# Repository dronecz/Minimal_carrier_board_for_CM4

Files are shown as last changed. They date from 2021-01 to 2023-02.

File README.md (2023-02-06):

# Minimal carrier board for Compute Module 4

This board is based on design from [Prof. Fartsparkle´s](https://hackaday.io/project/175832-minimal-raspberry-pi-cm-4-carrier). I made it 2 layer board and changed slot for SD card. 

If you are interested, I have some boards for you at my [Tindie](https://www.tindie.com/products/dronecz/minimal-carrier-board-for-compute-module-4/) store. 

You can also find STEP files for revision A and D in _STEP files_ directory. 

##### A designed following revisions:

- **rev.A**

This is just copy of the design from Timon. I just added 2x7 pin header and made shape of the board to the size of the Einsy board so I can use it for Octoprint. 

Board is tested and working. There is UART connection at that 2x7 pin header connected to the GPIO´s at CM4. There is slight problem with cables for HDMI and USB, but it can be solved with right cables.  

**WARNING** : The pinout for Einsy board is mirrored so I do not take any responsibility for damage which can be cause by this. You can change that in files and made your own board.

- **rev.B** 

I redesigned whole board and made it little bit bigger. Added 3.2mm mounting holes to each corner, added boot button for versions of CM4 with eMMC onboard (working), added connector for camera and added standard 40-pin header for Raspberry Pi.

I did not made this board yet but I did test distances between cables and rearanged them so they should not colide. Height of camera connector should be OK beneeth CM4, but this need to be tested. 

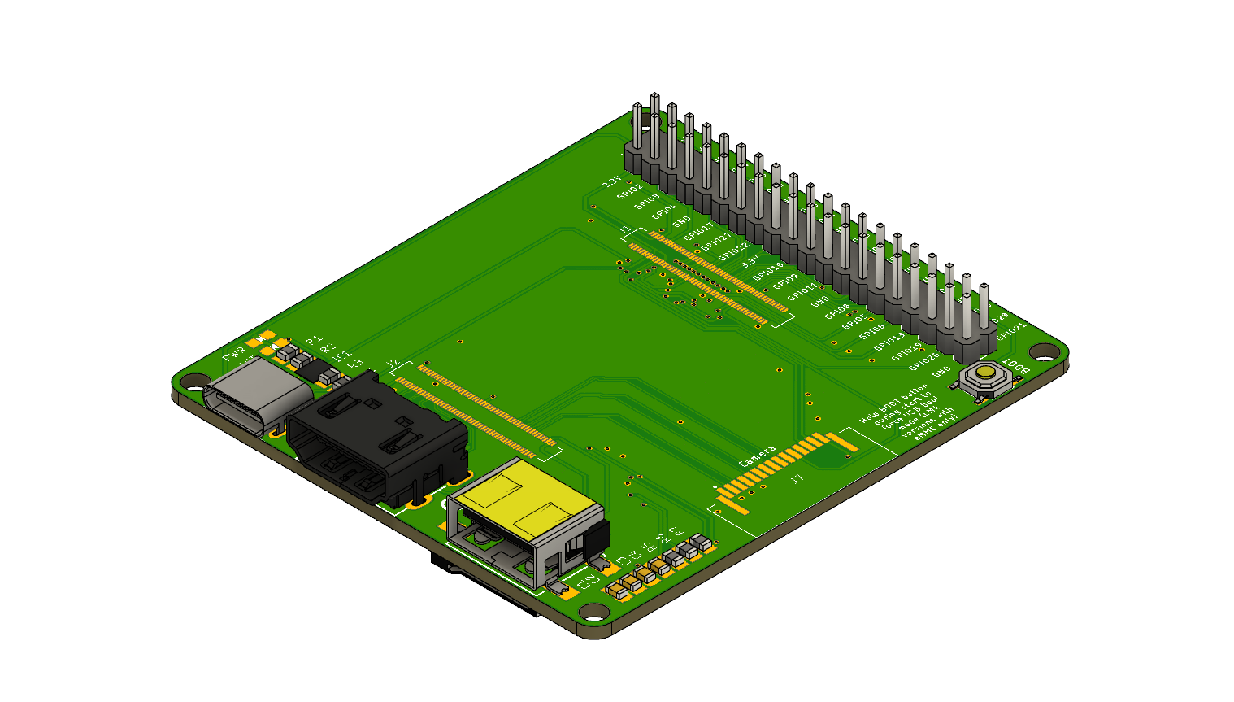
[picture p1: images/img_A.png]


- **rev.B_alt**

This is same board as rev.B, but there are 22-pin connectors which are same as those used at official IO board. 

This version of the board was not manufactured and probably will never be. 

- **rev.C**

Layout of the board is same with **rev.B** but I did move CM4 about 2 mm up and camera connector about 1 mm down. Half of the board was routed again .**This revision was not manufactured and it is not tested!** 

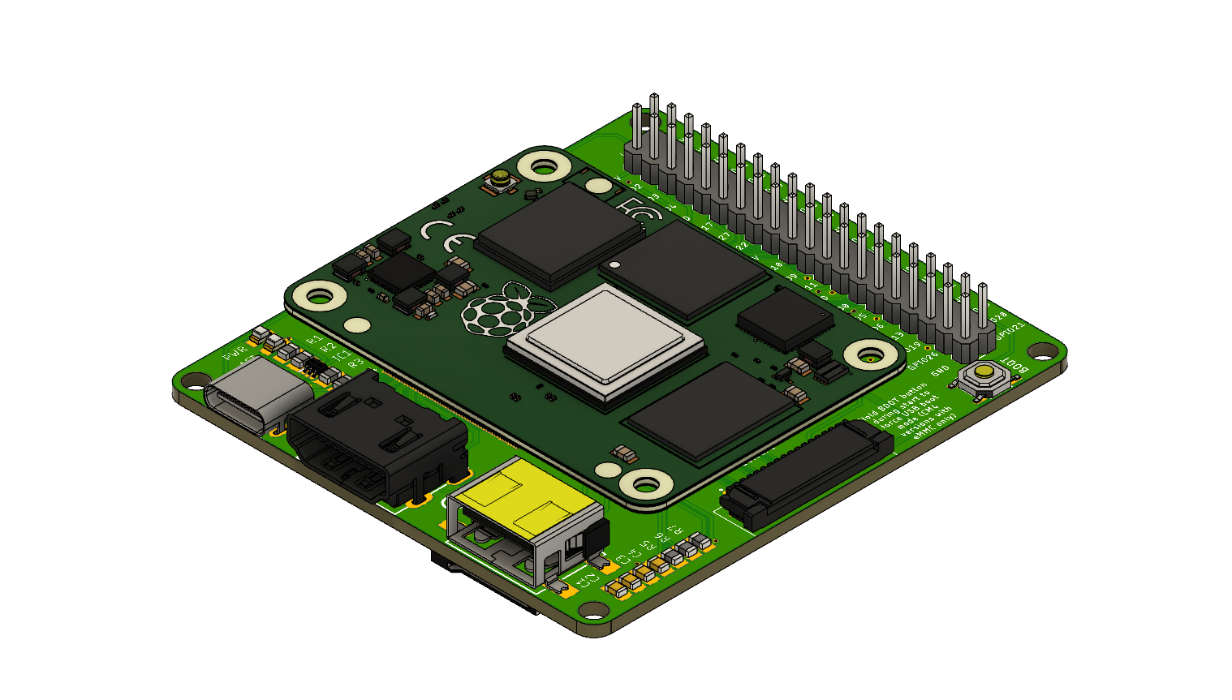
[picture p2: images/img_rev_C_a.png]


- **rev.D**

This version of the board is working, except camera connector because I did not routed camera connections as differential pairs. I made and sold about 30 boards without any complains, so the design is validated. 

- **rev.E**

This is same board as rev.D, but with differential pairs fix for camera connector. **This revision was not yet manufactured so I can not garantee that the connector for camera will work.**

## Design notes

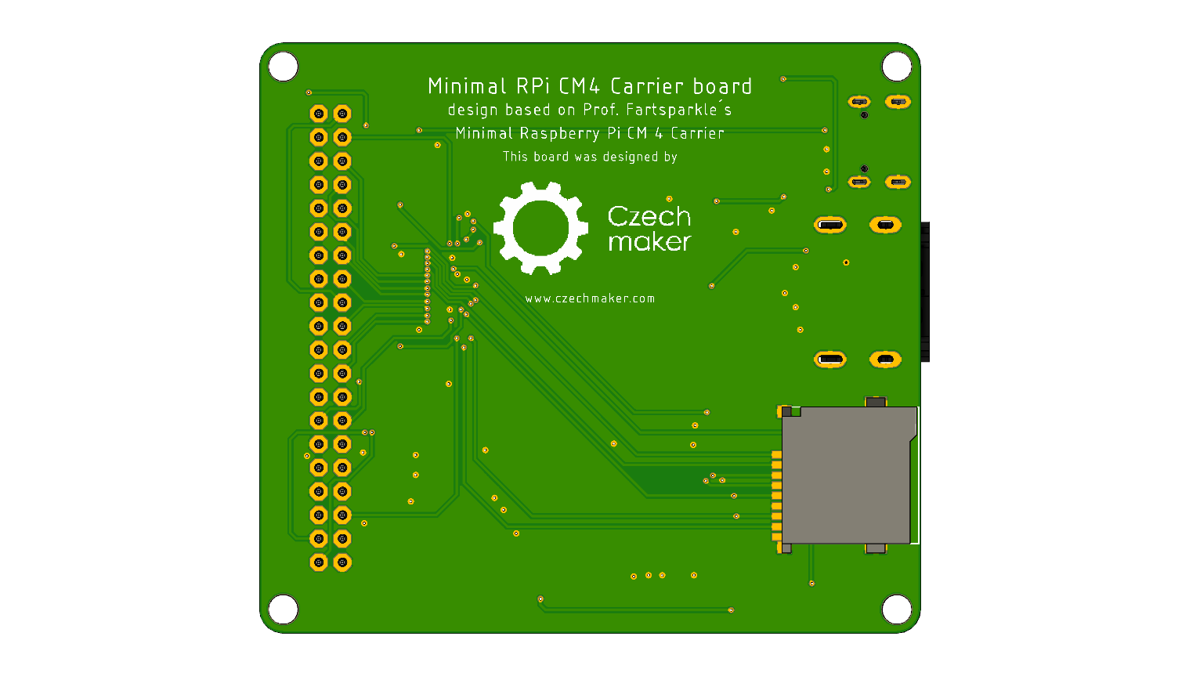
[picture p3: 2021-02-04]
images/img_C.png

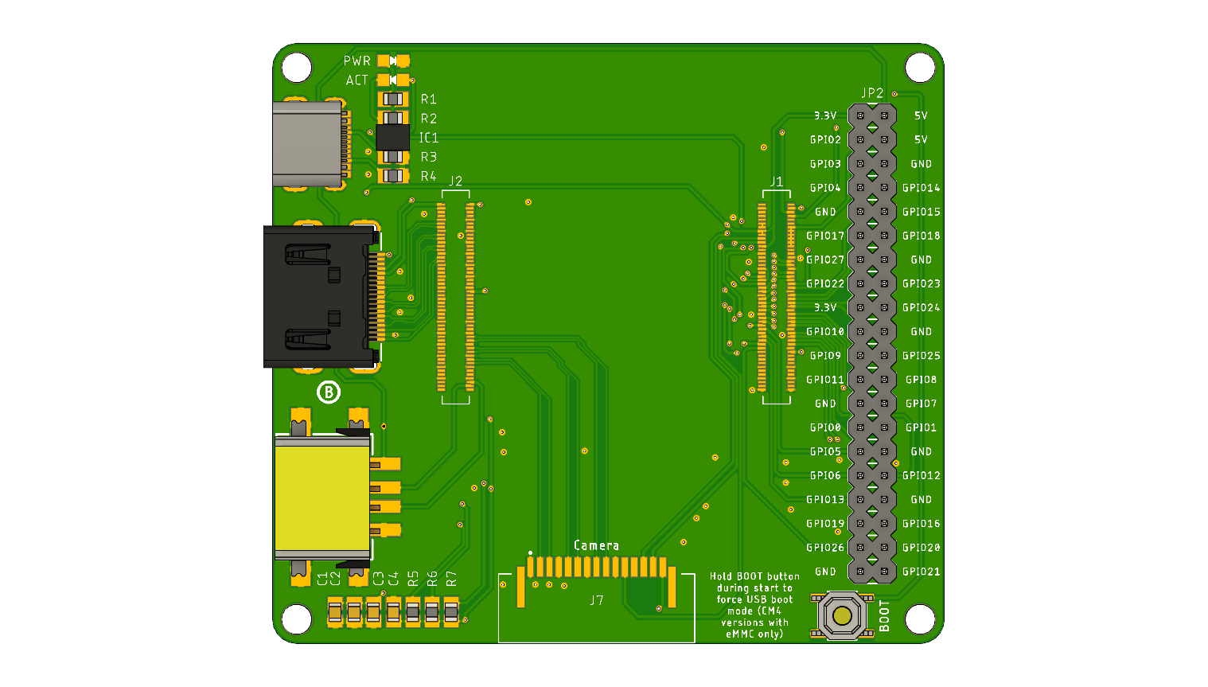
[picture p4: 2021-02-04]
images/img_B.png

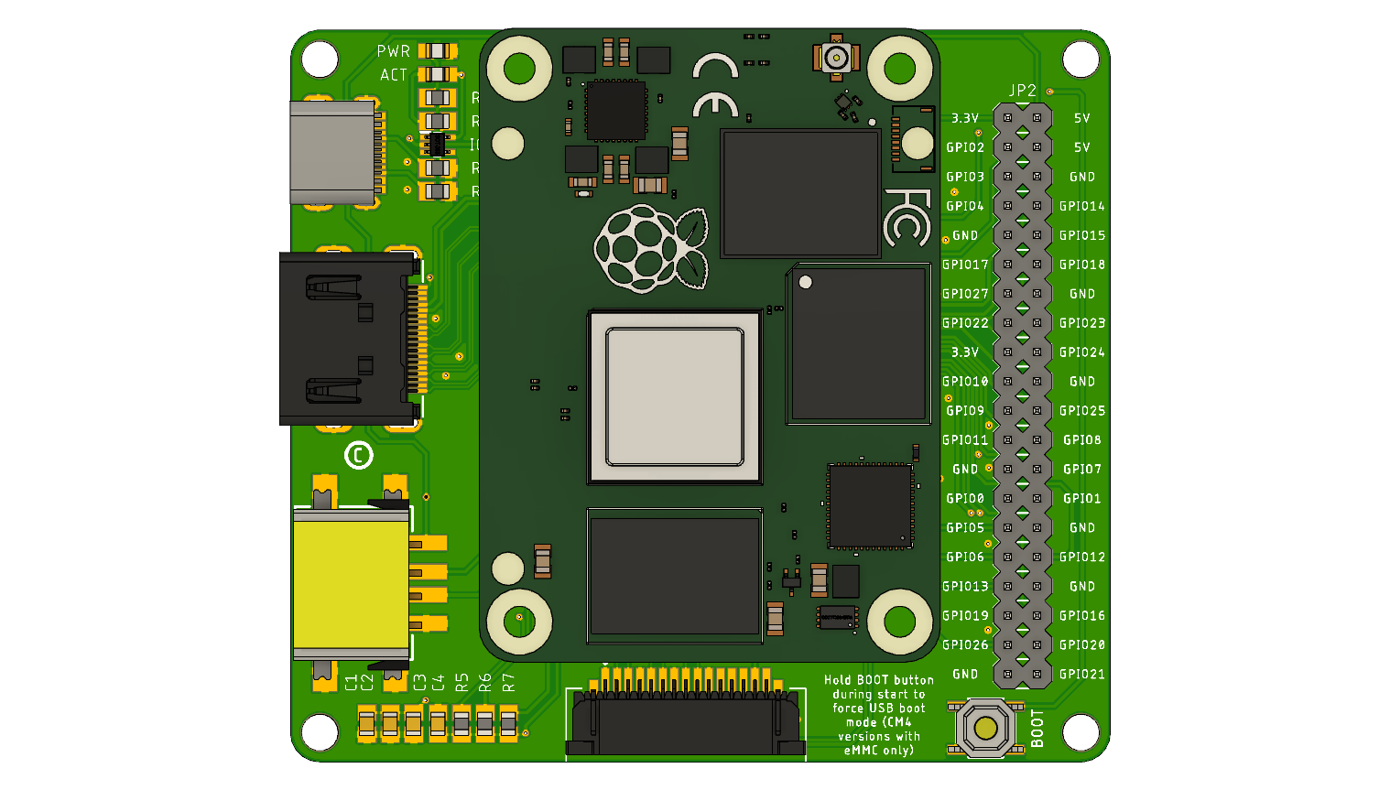
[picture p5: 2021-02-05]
images/img_rev_C_b.png

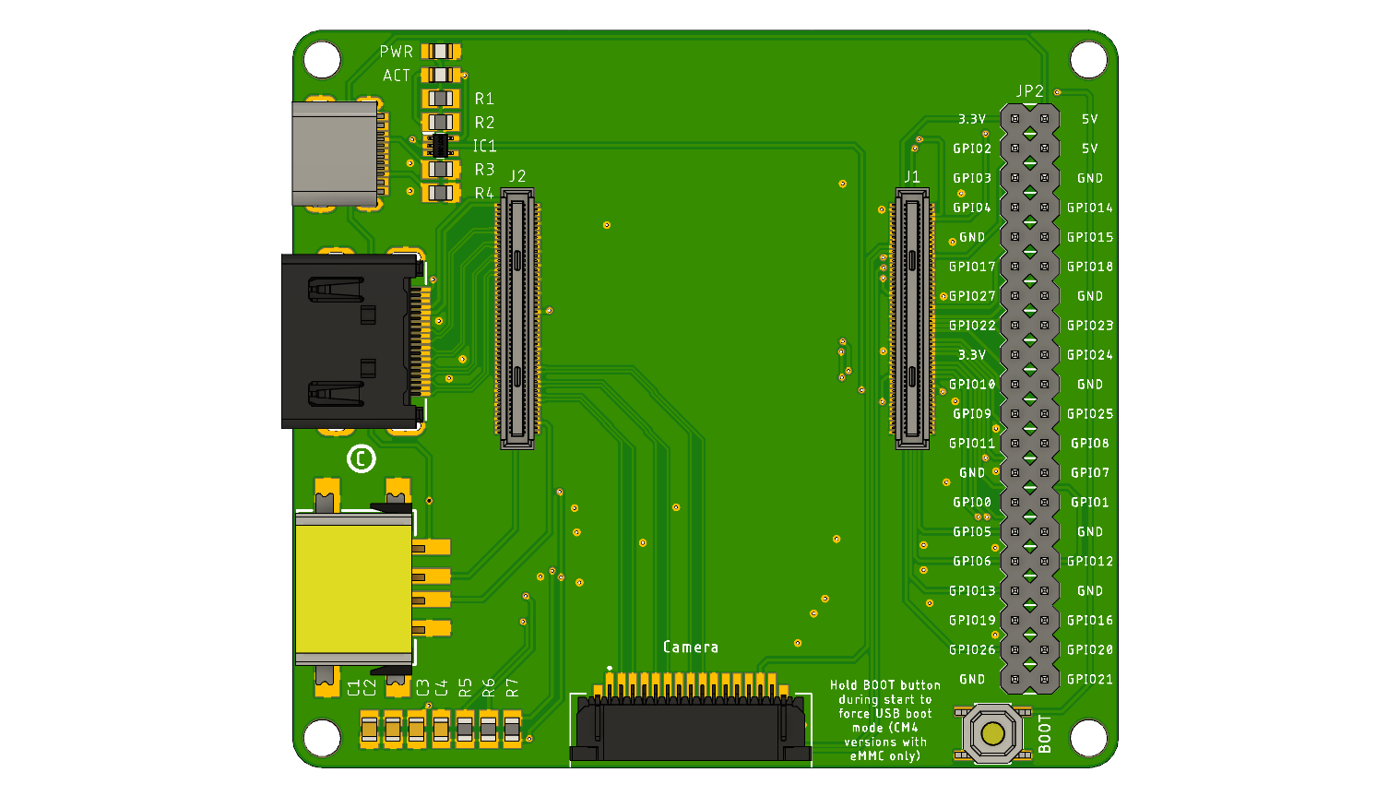
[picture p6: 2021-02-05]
images/img_rev_C_c.png

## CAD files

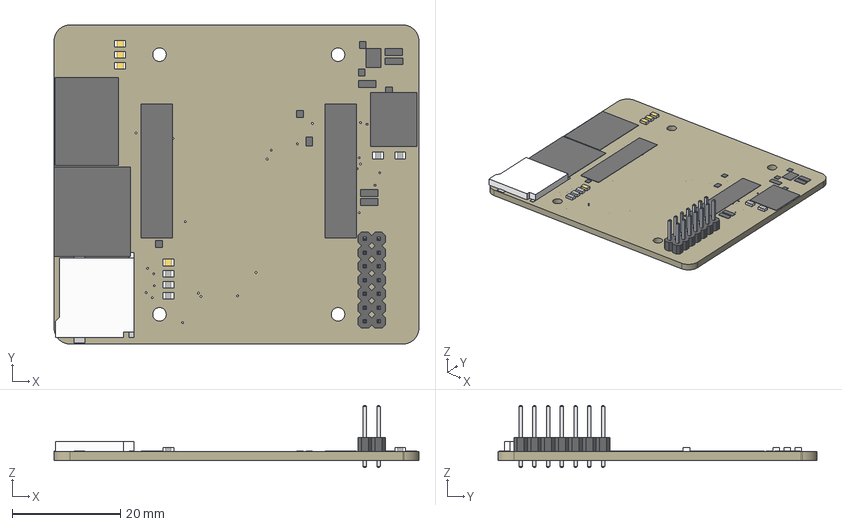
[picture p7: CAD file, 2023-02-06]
STEP files/Minimal_carrier_board_for_CM4_rev_A .step
67.5 x 59.0 x 11.5 mm
Board
USB-A-F-PTH
USB-TYPE-C_16PIN-MALE-TYPE-C-31-M-12
DF40C100DS04V51 x 2
SOT65P210X110-5N
PAD.03X.05 x 5
SMT-JUMPER_2_NC_TRACE_NO-SILK
TFP09-2--12B
CHIPLED_0805_NOOUTLINE x 2
HDMI_MOLEX_47151-0001
_0805MP x 3
2X07
C0805 x 4
R0805 x 5

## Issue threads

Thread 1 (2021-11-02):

Schematics pdf

jaksatomovic, 2021-11-02:
Can you please share schematics in pdf format, since this can't be opened in KiCad? Thx

dronecz, 2021-11-02:
HI,

I can, but which version you have in mind? I do not use it, but I know that KiCad can import Eagle projects.

jaksatomovic, 2021-11-02:
Hi, thx for the quick reply. I was thinking on latest version…C

dronecz, 2021-11-02:
[Here](https://github.com/dronecz/Minimal_carrier_board_for_CM4/blob/main/rev_C/Minimal_carrier_board_for_CM4_rev_C.pdf) you have it 😉

jaksatomovic, 2021-11-02:
Thank you!

Closed 2021-11-02.

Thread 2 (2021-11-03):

Csi; cam1 missing datalines 2 and 3

rraat, 2021-11-03:
Unfortunataly the csi interface is a 15 pin connector and the 2 additional data lines are not implememted
Would be great if the csi connector could be replaced with a mini connector (22 pin as found on the pi zero) that way we could attach a tc358743 module for hdmi input)

dronecz, 2021-11-03:
I choosed CSI connector so you can use RPi Camera module straight away without any reduction or without need of 22 to 15 pin cable which is used for RPI Zero. Connector is wired per CM4 IO board schematic:
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

I do not plan to change connector or add other lines, but you can do so, as you have all files which you need for that.

samveen, 2021-11-06:
As someone who had to purchase the 22 to 15 pin cable, I find the full sized connector way more useful, given that the correct cable is supplied along with most camera modules in the Raspberry Pi ecosystem.

munjeni, 2023-12-29:
You pcb is very bad, simply bad layout. Too long data lines act as an high freq antena. Too long 3.3V lie, it going to pickup all noise from fast daa lines. Also you must separate ground from signal ground and connect it at input supply capacitor in star coonection at one point at supply input capacitor. You must have 4 layer pcb and put supply lines/gnd line inside central layers, lines one over other to form an small capicitivity and have less noise pickup, fast data lines on top layer only, bottom layer as a shield layer call it gndref laye cnnected with all other gndref layer shields, connect all gndref layers at one point in star at supply input capacitor... etc.

dronecz, 2023-12-29:
> Your pcb is bad, simply bad layout. Too long data lines act as an high freq antena. Too long 3.3V lines, it going to pickup all noise from fast data lines. Also you must separate ground from signal ground and connect it at input supply capacitor in star coonection at one point at supply input capacitor. You must have 4 layer pcb and put supply lines/gnd line inside central layers, lines one over other to form an small capicitivity and have less noise pickup, fast data lines on top layer only, bottom layer as a shield layer call it gndref layer cnnected with all other gndref layers, connect all gndref layers at one point in star at a one point at a supply input capacitor. Lack of boiler capacitors, lack of supression capacitors... etc.. Put camera connector, usb connector, hdmi connector as close as possible to cm4 pins. Put signaling led on bottom/right side. Layout is very bad. The only thing which I like is it looks nice, the other things very bad.

Thank you for your review. If you do not like it, then you can fork it, make it better and I would merge your PR.

munjeni, 2023-12-30:
Your pcb looks good, you started it nice but I not like how you route thing, I will do it when I get some free time! I just started routing it, looks better? RefGND is a star point where your signal gnd lines must be routed, group it, for example group gnd signal lines from for example sd card and route to the star gndref, than the same for e.g. hdmi ground lines... etc. The same for 5V and 3.3V. GND from sockets metal can be routed directly to big gnd line but. All signal lines put on top layer only... See example!
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

munjeni, 2023-12-30:
Some more work
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

munjeni, 2023-12-30:
For you from me and for me too! Complete project files, pictures, schematic, gerber, bom. All shield layers is connected in star ground as all other gnd things. Supply lines isolated, signal lines isolated too. I done my best to route it correctly, hope it will be usefull.

[MinimalCarrierBoardForCM4_Munjeni.zip](https://github.com/dronecz/Minimal_carrier_board_for_CM4/files/13798436/MinimalCarrierBoardForCM4_Munjeni.zip)

munjeni, 2023-12-30:
Oh sorry, one hole was covered by sdcard slot, this is corrected gerber file

[Gerber_PCB_MinimalCarrierBoardForCM4.zip](https://github.com/dronecz/Minimal_carrier_board_for_CM4/files/13798978/Gerber_PCB_MinimalCarrierBoardForCM4.zip)

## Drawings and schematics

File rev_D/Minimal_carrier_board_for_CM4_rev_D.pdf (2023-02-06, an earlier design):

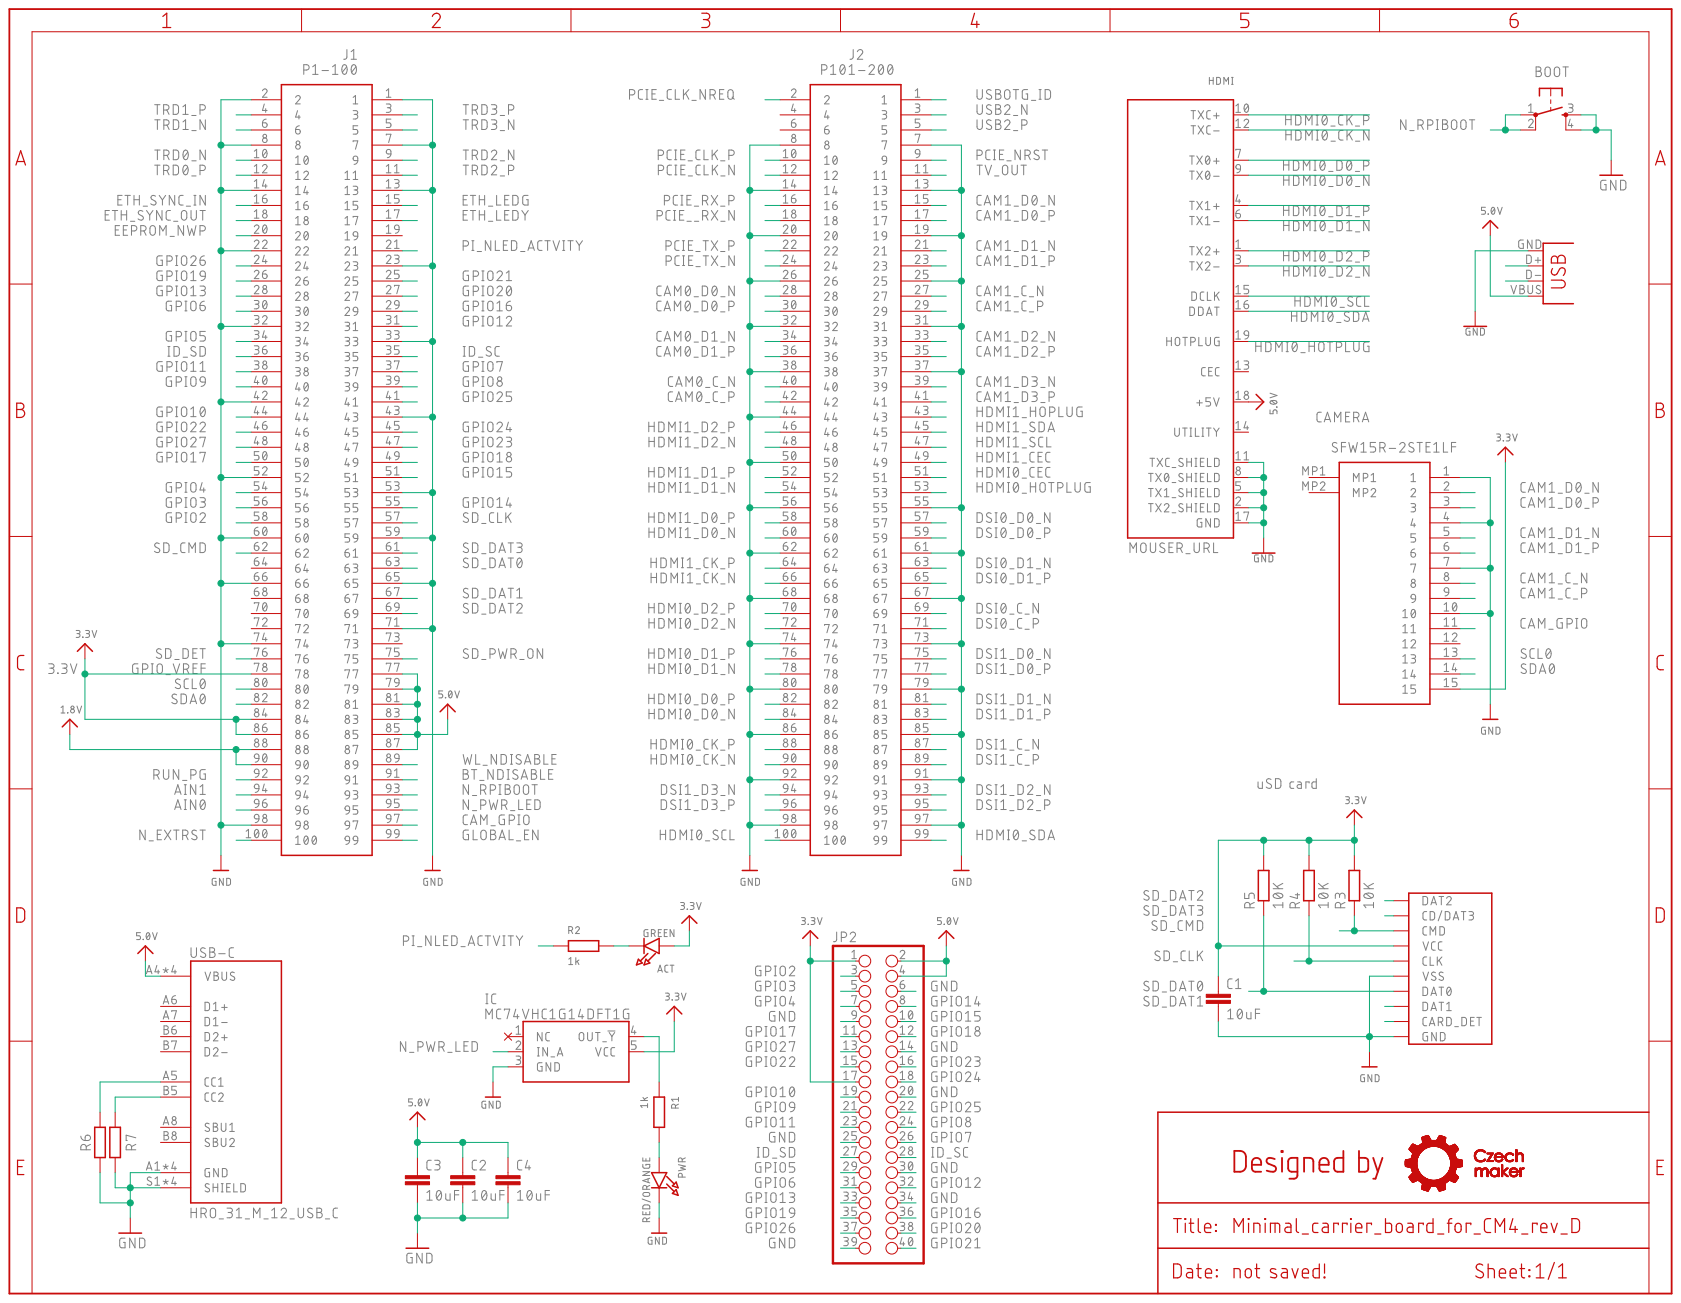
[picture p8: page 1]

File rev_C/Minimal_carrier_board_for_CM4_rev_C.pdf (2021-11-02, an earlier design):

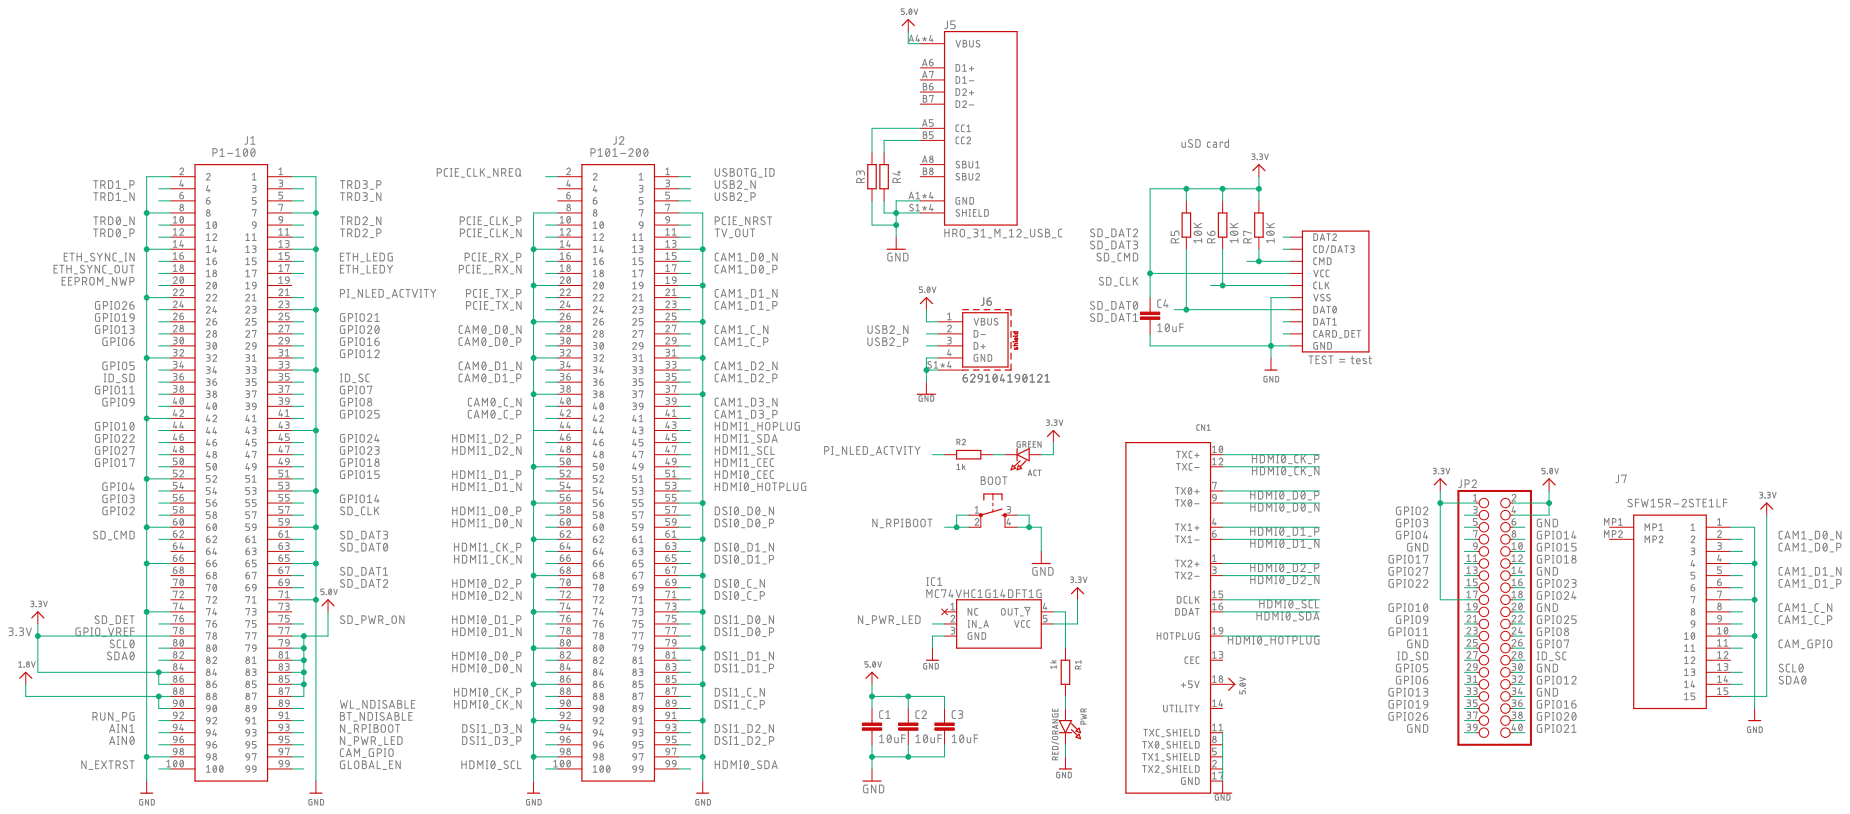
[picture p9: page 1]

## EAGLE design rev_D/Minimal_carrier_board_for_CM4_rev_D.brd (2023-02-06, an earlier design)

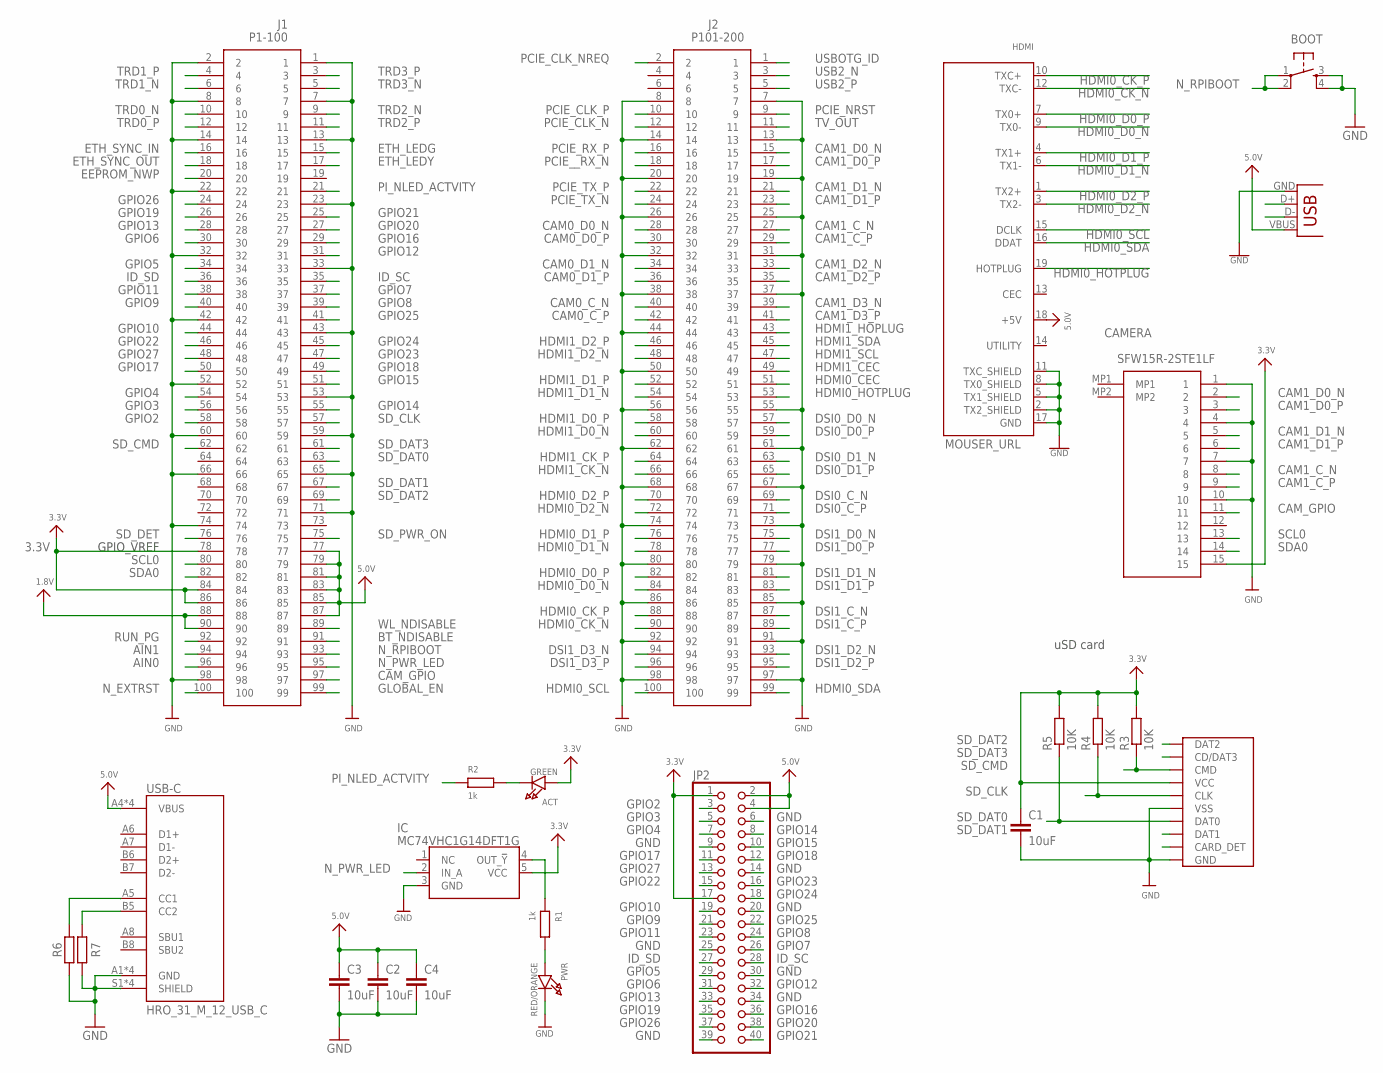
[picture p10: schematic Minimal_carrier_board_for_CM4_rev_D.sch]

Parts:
ACT: GREEN; CHIPLED_0805_NOOUTLINE
BOOT: TACTILE_SWITCHE_5X5_MICRO_; TACTILE_SWITCH_5X5_MICRO
C1, C2, C3, C4: 10uF; C0805
CAMERA: SFW15R-2STE1LF; SFW15R2STE1LF
HDMI: HDMI_MOLEX_47151-0001
IC: MC74VHC1G14DFT1G; SOT65P210X110-5N
J1: P1-100; DF40C100DS04V51
J2: P101-200; DF40C100DS04V51
JP2: PINHD-2X20; 2X20
PWR: RED/ORANGE; CHIPLED_0805_NOOUTLINE
R1, R2: 1k; R0805
R3, R4, R5: 10K; R0805
R6, R7: 5.1k; R0805
SD_CARD: MICRO_SD_CARD_; TFP09-2--12B
USB-A: USBA-PTH; USB-A-F-PTH
USB-C: HRO_31_M_12_USB_C

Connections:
1.8V: J1.88, J1.90
3.3V: ACT.A, C1.1, CAMERA.15, IC.5 (VCC), J1.78, J1.84, J1.86, JP2.1, JP2.17, R3.2, R4.2, R5.2, SD_CARD.VCC
5.0V: C2.1, C3.1, C4.1, HDMI.18 (+5V), J1.77, J1.79, J1.81, J1.83, J1.85, J1.87, JP2.2, JP2.4, USB-A.VBUS, USB-C.A4 (VBUS), USB-C.A9 (VBUS), USB-C.B4 (VBUS), USB-C.B9 (VBUS)
AIN0: J1.96
AIN1: J1.94
BT_NDISABLE: J1.91
CAM0_C_N: J2.40
CAM0_C_P: J2.42
CAM0_D0_N: J2.28
CAM0_D0_P: J2.30
CAM0_D1_N: J2.34
CAM0_D1_P: J2.36
CAM1_C_N: CAMERA.8, J2.27
CAM1_C_P: CAMERA.9, J2.29
CAM1_D0_N: CAMERA.2, J2.15
CAM1_D0_P: CAMERA.3, J2.17
CAM1_D1_N: CAMERA.5, J2.21
CAM1_D1_P: CAMERA.6, J2.23
CAM1_D2_N: J2.33
CAM1_D2_P: J2.35
CAM1_D3_N: J2.39
CAM1_D3_P: J2.41
CAM_GPIO: CAMERA.11, J1.97
DSI0_C_N: J2.69
DSI0_C_P: J2.71
DSI0_D0_N: J2.57
DSI0_D0_P: J2.59
DSI0_D1_N: J2.63
DSI0_D1_P: J2.65
DSI1_C_N: J2.87
DSI1_C_P: J2.89
DSI1_D0_N: J2.75
DSI1_D0_P: J2.77
DSI1_D1_N: J2.81
DSI1_D1_P: J2.83
DSI1_D2_N: J2.93
DSI1_D2_P: J2.95
DSI1_D3_N: J2.94
DSI1_D3_P: J2.96
EEPROM_NWP: J1.20
ETH_LEDG: J1.15
ETH_LEDY: J1.17
ETH_SYNC_IN: J1.16
ETH_SYNC_OUT: J1.18
GLOBAL_EN: J1.99
GND: BOOT.3, BOOT.4, C1.2, C2.2, C3.2, C4.2, CAMERA.1, CAMERA.4, CAMERA.7, CAMERA.10, HDMI.2 (TX2_SHIELD), HDMI.5 (TX1_SHIELD), HDMI.8 (TX0_SHIELD), HDMI.11 (TXC_SHIELD), HDMI.17 (GND), HDMI.P$1 (GND), HDMI.P$2 (GND), HDMI.P$3 (GND), HDMI.P$4 (GND), IC.3 (GND), J1.1, J1.2, J1.7, J1.8, J1.13, J1.14, J1.22, J1.23, J1.32, J1.33, J1.42, J1.43, J1.52, J1.53, J1.59, J1.60, J1.65, J1.66, J1.71, J1.74, J1.98, J2.7, J2.8, J2.13, J2.14, J2.19, J2.20, J2.25, J2.26, J2.31, J2.32, J2.37, J2.38, J2.44, J2.50, J2.55, J2.56, J2.61, J2.62, J2.67, J2.68, J2.73, J2.74, J2.79, J2.80, J2.85, J2.86, J2.91, J2.92, J2.97, J2.98, JP2.6, JP2.9, JP2.14, JP2.20, JP2.25, JP2.30, JP2.34, JP2.39, PWR.C, R6.1, R7.2, SD_CARD.GND, SD_CARD.GND@1 (GND), SD_CARD.GND@2 (GND), SD_CARD.GND@3 (VSS), SD_CARD.VSS (GND), USB-A.GND, USB-C.A1 (GND), USB-C.A12 (GND), USB-C.B1 (GND), USB-C.B12 (GND), USB-C.S1 (SHIELD), USB-C.S2 (SHIELD), USB-C.S3 (SHIELD), USB-C.S4 (SHIELD)
GPIO2: J1.58, JP2.3
GPIO3: J1.56, JP2.5
GPIO4: J1.54, JP2.7
GPIO5: J1.34, JP2.29
GPIO6: J1.30, JP2.31
GPIO7: J1.37, JP2.26
GPIO8: J1.39, JP2.24
GPIO9: J1.40, JP2.21
GPIO10: J1.44, JP2.19
GPIO11: J1.38, JP2.23
GPIO12: J1.31, JP2.32
GPIO13: J1.28, JP2.33
GPIO14: J1.55, JP2.8
GPIO15: J1.51, JP2.10
GPIO16: J1.29, JP2.36
GPIO17: J1.50, JP2.11
GPIO18: J1.49, JP2.12
GPIO19: J1.26, JP2.35
GPIO20: J1.27, JP2.38
GPIO21: J1.25, JP2.40
GPIO22: J1.46, JP2.15
GPIO23: J1.47, JP2.16
GPIO24: J1.45, JP2.18
GPIO25: J1.41, JP2.22
GPIO26: J1.24, JP2.37
GPIO27: J1.48, JP2.13
HDMI0_CEC: J2.51
HDMI0_CK_N: HDMI.12 (TXC-), J2.90
HDMI0_CK_P: HDMI.10 (TXC+), J2.88
HDMI0_D0_N: HDMI.9 (TX0-), J2.84
HDMI0_D0_P: HDMI.7 (TX0+), J2.82
HDMI0_D1_N: HDMI.6 (TX1-), J2.78
HDMI0_D1_P: HDMI.4 (TX1+), J2.76
HDMI0_D2_N: HDMI.3 (TX2-), J2.72
HDMI0_D2_P: HDMI.1 (TX2+), J2.70
HDMI0_HOTPLUG: HDMI.19 (HOTPLUG), J2.53
HDMI0_SCL: HDMI.15 (DCLK), J2.100
HDMI0_SDA: HDMI.16 (DDAT), J2.99
HDMI1_CEC: J2.49
HDMI1_CK_N: J2.66
HDMI1_CK_P: J2.64
HDMI1_D0_N: J2.60
HDMI1_D0_P: J2.58
HDMI1_D1_N: J2.54
HDMI1_D1_P: J2.52
HDMI1_D2_N: J2.48
HDMI1_D2_P: J2.46
HDMI1_HOPLUG: J2.43
HDMI1_SCL: J2.47
HDMI1_SDA: J2.45
ID_SC: J1.35, JP2.28
ID_SD: J1.36, JP2.27
unnamed: ACT.C, R2.2
unnamed: PWR.A, R1.2
unnamed: R6.2, USB-C.A5 (CC1)
unnamed: R7.1, USB-C.B5 (CC2)
unnamed: IC.4 (OUT_!Y), R1.1
N_EXTRST: J1.100
N_PWR_LED: IC.2 (IN_A), J1.95
N_RPIBOOT: BOOT.1, BOOT.2, J1.93
PCIE_CLK_N: J2.12
PCIE_CLK_NREQ: J2.2
PCIE_CLK_P: J2.10
PCIE_NRST: J2.9
PCIE_RX_P: J2.16
PCIE_TX_N: J2.24
PCIE_TX_P: J2.22
PCIE__RX_N: J2.18
PI_NLED_ACTVITY: J1.21, R2.1
RUN_PG: J1.92
SCL0: CAMERA.13, J1.80
SDA0: CAMERA.14, J1.82
SD_CLK: J1.57, R4.1, SD_CARD.CLK
SD_CMD: J1.62, R3.1, SD_CARD.CMD
SD_DAT0: J1.63, R5.1, SD_CARD.DAT0
SD_DAT1: J1.67, SD_CARD.DAT1
SD_DAT2: J1.69, SD_CARD.DAT2
SD_DAT3: J1.61, SD_CARD.CD/DAT3
SD_DET: J1.76
SD_PWR_ON: J1.75
TRD0_N: J1.10
TRD0_P: J1.12
TRD1_N: J1.6
TRD1_P: J1.4
TRD2_N: J1.9
TRD2_P: J1.11
TRD3_N: J1.5
TRD3_P: J1.3
TV_OUT: J2.11
USB2_N: J2.3, USB-A.D-
USB2_P: J2.5, USB-A.D+
USBOTG_ID: J2.1
WL_NDISABLE: J1.89

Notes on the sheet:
uSD card
GPIO_VREF

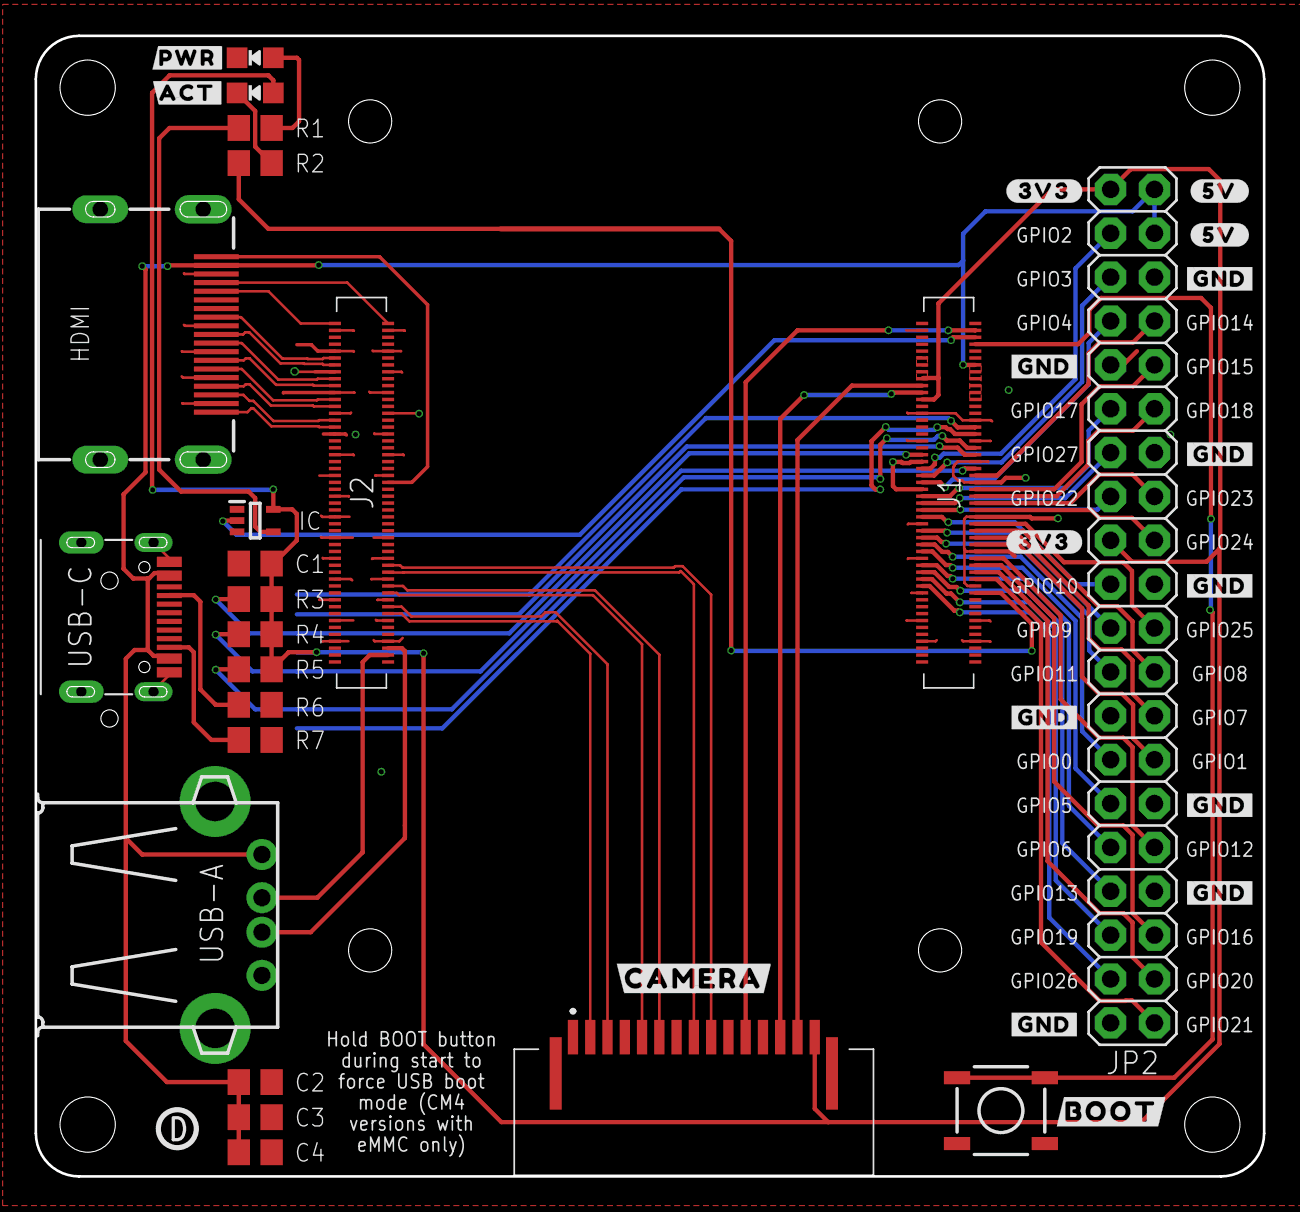
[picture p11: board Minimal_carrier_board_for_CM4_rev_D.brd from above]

Board: 2 copper layers, 71.1 x 66.0 mm, 39 parts (1 on the bottom side), 68 nets.

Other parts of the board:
U$6, U$7, U$8, U$9, U$10, U$11, U$12, U$13: #GND#0
U$14, U$15: #5V#0
U$16, U$17: #3V3#0
U$18: #PWR#0
U$19: #ACT#0
U$20: #CAMERA#0
U$21: #BOOT#0

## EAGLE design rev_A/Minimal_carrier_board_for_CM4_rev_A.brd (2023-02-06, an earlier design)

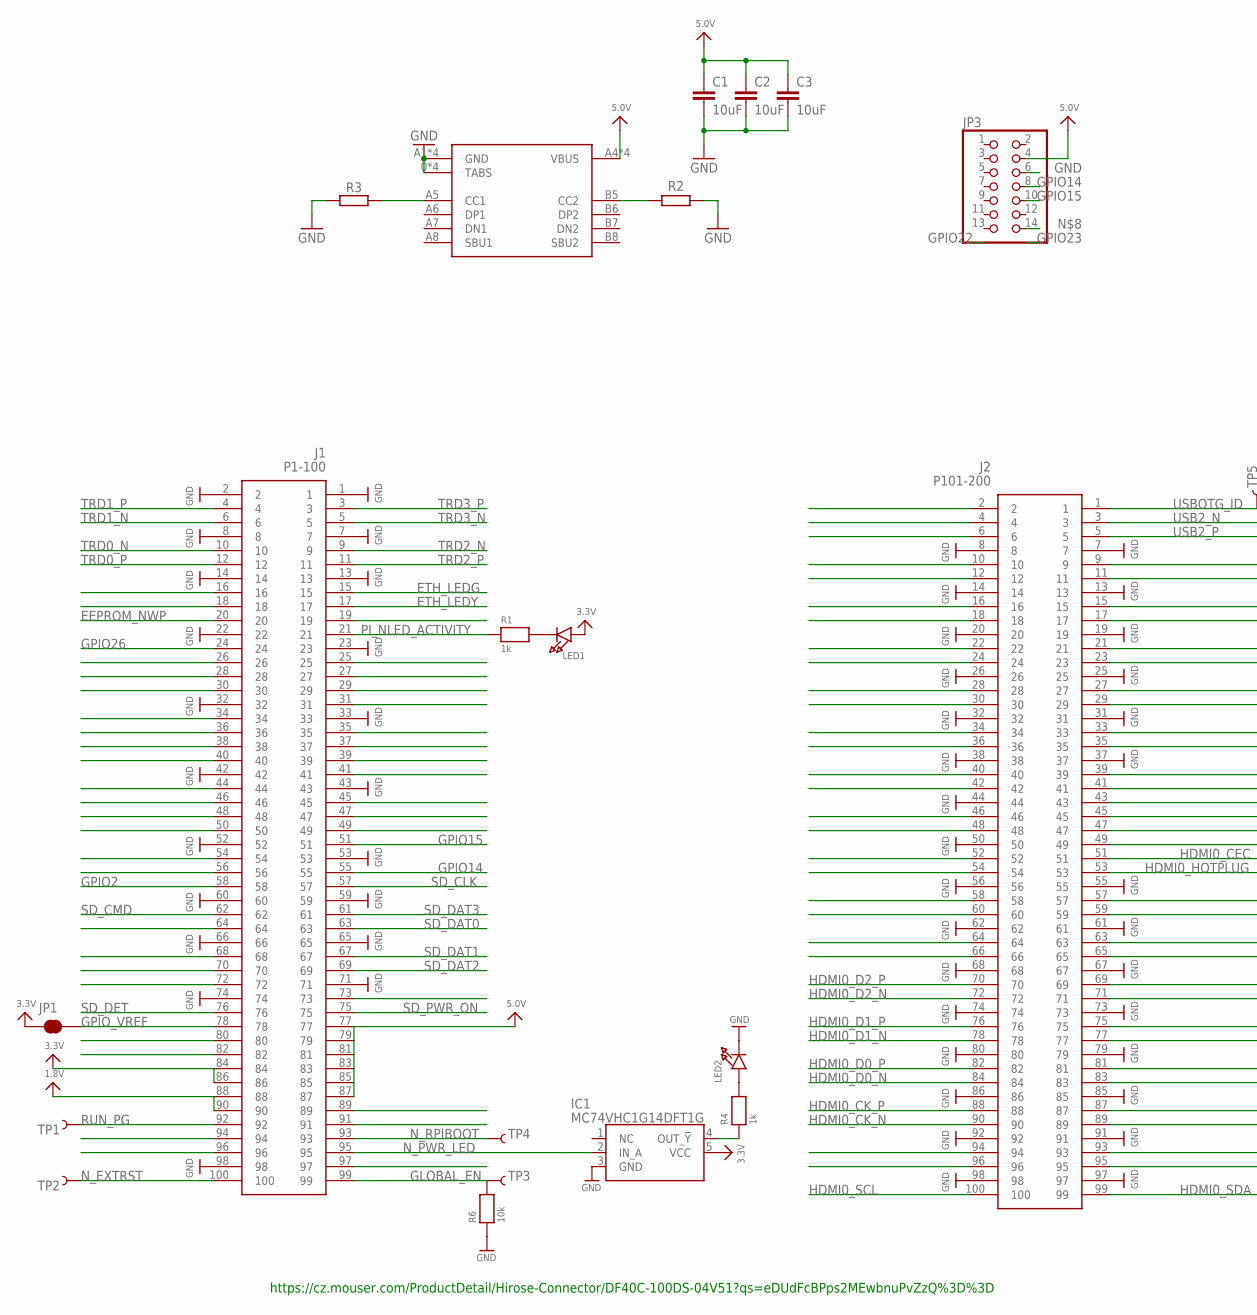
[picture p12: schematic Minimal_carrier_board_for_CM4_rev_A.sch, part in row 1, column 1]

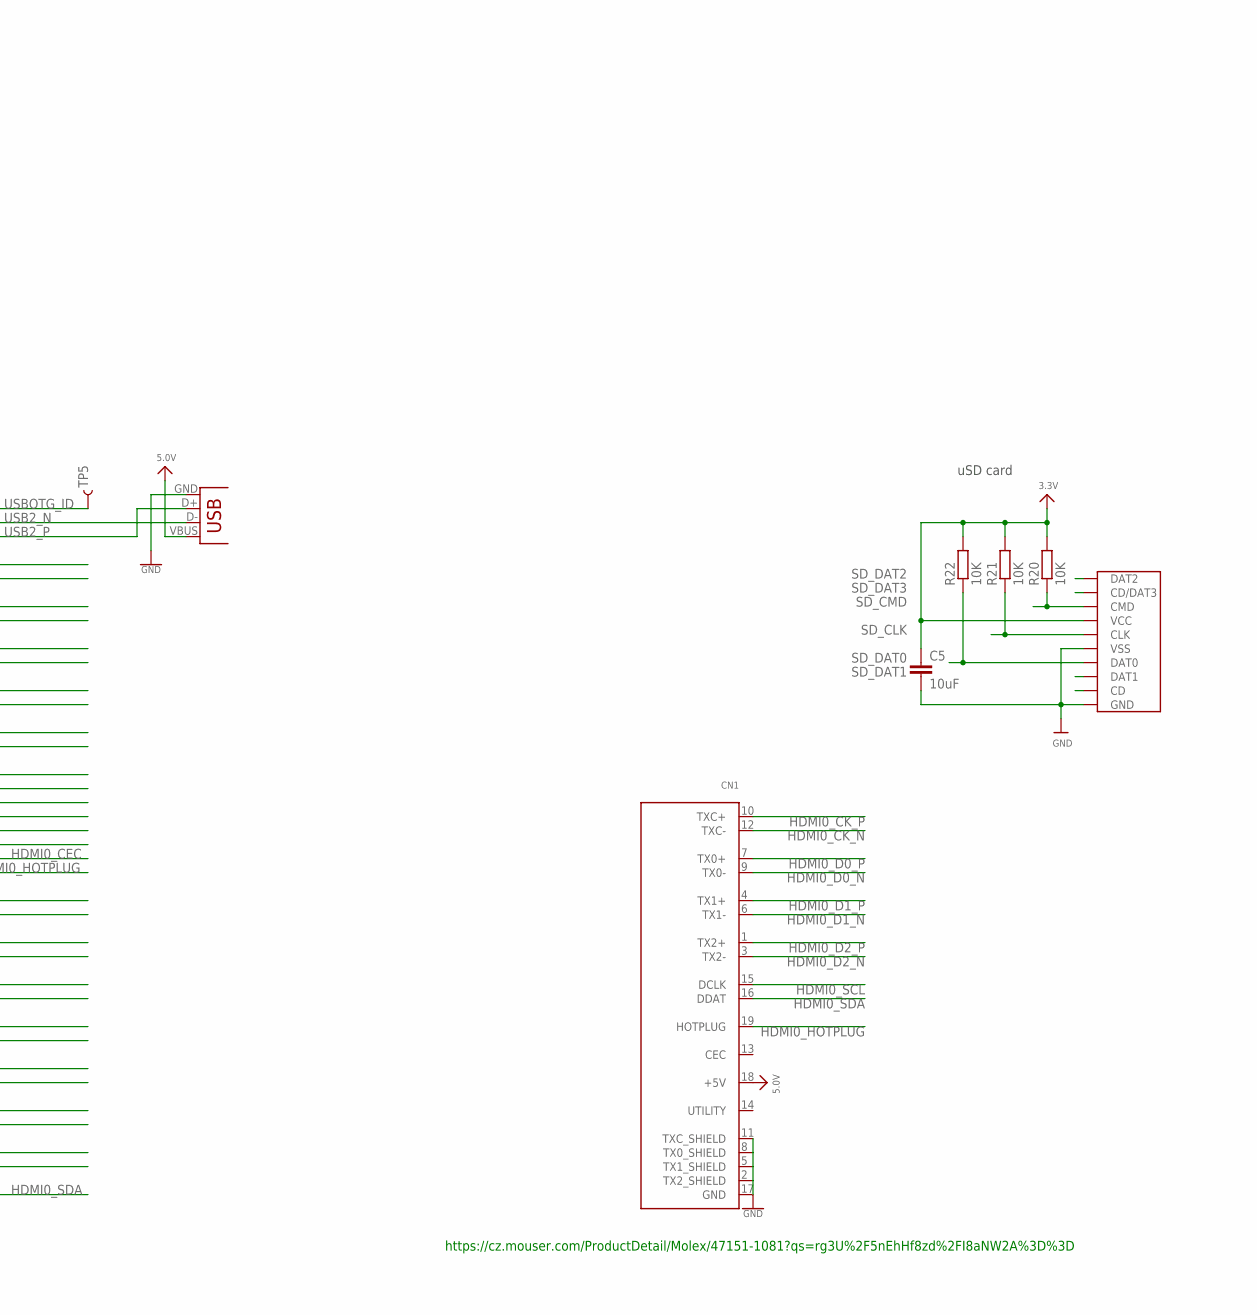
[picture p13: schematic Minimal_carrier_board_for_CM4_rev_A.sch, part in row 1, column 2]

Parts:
C1, C2, C3, C5: 10uF; C0805
CN1: HDMI_MOLEX_47151-0001
IC1: MC74VHC1G14DFT1G; SOT65P210X110-5N
J1: P1-100; DF40C100DS04V51
J2: P101-200; DF40C100DS04V51
JP1: JUMPER-SMT_2_NC_TRACE_NO-SILK; SMT-JUMPER_2_NC_TRACE_NO-SILK
JP3: PINHD-2X7; 2X07
LED1, LED2: LED0805_NOOUTLINE; CHIPLED_0805_NOOUTLINE
R1, R4: 1k; _0805MP
R2, R3: 5.1k; R0805
R6: 10k; _0805MP
R20, R21, R22: 10K; R0805
SD_CARD: MICRO_SD_CARD_; TFP09-2--12B
TP1, TP2, TP3, TP4, TP5: TEST-POINT3X5; PAD.03X.05
U$59: TYPE-C-31-M-12; USB-TYPE-C_16PIN-MALE-TYPE-C-31-M-12
USB2: USBA-PTH; USB-A-F-PTH

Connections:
1.8V: J1.88, J1.90
3.3V: C5.1, IC1.5 (VCC), J1.84, J1.86, JP1.1, LED1.A, R20.2, R21.2, R22.2, SD_CARD.VCC
5.0V: C1.1, C2.1, C3.1, CN1.18 (+5V), J1.77, J1.79, J1.81, J1.83, J1.85, J1.87, JP3.4, U$59.A4 (VBUS), U$59.A9 (VBUS), U$59.B4 (VBUS), U$59.B9 (VBUS), USB2.VBUS
A0/CC2: R3.2, U$59.A5 (CC1)
A3/CC1: R2.1, U$59.B5 (CC2)
EEPROM_NWP: J1.20
ETH_LEDG: J1.15
ETH_LEDY: J1.17
GLOBAL_EN: J1.99, R6.2, TP3.P$1
GND: C1.2, C2.2, C3.2, C5.2, CN1.2 (TX2_SHIELD), CN1.5 (TX1_SHIELD), CN1.8 (TX0_SHIELD), CN1.11 (TXC_SHIELD), CN1.17 (GND), CN1.P$1 (GND), CN1.P$2 (GND), CN1.P$3 (GND), CN1.P$4 (GND), IC1.3 (GND), J1.1, J1.2, J1.7, J1.8, J1.13, J1.14, J1.22, J1.23, J1.32, J1.33, J1.42, J1.43, J1.52, J1.53, J1.59, J1.60, J1.65, J1.66, J1.71, J1.74, J1.98, J2.7, J2.8, J2.13, J2.14, J2.19, J2.20, J2.25, J2.26, J2.31, J2.32, J2.37, J2.38, J2.44, J2.50, J2.55, J2.56, J2.61, J2.62, J2.67, J2.68, J2.73, J2.74, J2.79, J2.80, J2.85, J2.86, J2.91, J2.92, J2.97, J2.98, JP3.6, LED2.C, R2.2, R3.1, R6.1, SD_CARD.GND, SD_CARD.GND@1 (GND), SD_CARD.GND@2 (GND), SD_CARD.GND@3 (VSS), SD_CARD.VSS (GND), U$59.0 (TABS), U$59.0-1 (TABS), U$59.0-2 (TABS), U$59.0-3 (TABS), U$59.A1 (GND), U$59.A12 (GND), U$59.B1 (GND), U$59.B12 (GND), USB2.GND
GPIO2: J1.58
GPIO14: J1.55, JP3.8
GPIO15: J1.51, JP3.10
GPIO26: J1.24
GPIO_VREF: J1.78, JP1.2
HDMI0_CEC: J2.51
HDMI0_CK_N: CN1.12 (TXC-), J2.90
HDMI0_CK_P: CN1.10 (TXC+), J2.88
HDMI0_D0_N: CN1.9 (TX0-), J2.84
HDMI0_D0_P: CN1.7 (TX0+), J2.82
HDMI0_D1_N: CN1.6 (TX1-), J2.78
HDMI0_D1_P: CN1.4 (TX1+), J2.76
HDMI0_D2_N: CN1.3 (TX2-), J2.72
HDMI0_D2_P: CN1.1 (TX2+), J2.70
HDMI0_HOTPLUG: CN1.19 (HOTPLUG), J2.53
HDMI0_SCL: CN1.15 (DCLK), J2.100
HDMI0_SDA: CN1.16 (DDAT), J2.99
unnamed: LED1.C, R1.2
unnamed: IC1.4 (OUT_!Y), R4.1
unnamed: LED2.A, R4.2
N_EXTRST: J1.100, TP2.P$1
N_PWR_LED: IC1.2 (IN_A), J1.95
N_RPIBOOT: J1.93, TP4.P$1
PI_NLED_ACTIVITY: J1.21, R1.1
RUN_PG: J1.92, TP1.P$1
SD_CLK: J1.57, R21.1, SD_CARD.CLK
SD_CMD: J1.62, R20.1, SD_CARD.CMD
SD_DAT0: J1.63, R22.1, SD_CARD.DAT0
SD_DAT1: J1.67, SD_CARD.DAT1
SD_DAT2: J1.69, SD_CARD.DAT2
SD_DAT3: J1.61, SD_CARD.CD/DAT3
SD_DET: J1.76
SD_PWR_ON: J1.75
TRD0_N: J1.10
TRD0_P: J1.12
TRD1_N: J1.6
TRD1_P: J1.4
TRD2_N: J1.9
TRD2_P: J1.11
TRD3_N: J1.5
TRD3_P: J1.3
USB2_N: J2.3, USB2.D-
USB2_P: J2.5, USB2.D+
USBOTG_ID: J2.1, TP5.P$1

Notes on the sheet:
uSD card
https://cz.mouser.com/ProductDetail/Molex/47151-1081?qs=rg3U%2F5nEhHf8zd%2FI8aNW2A%3D%3D
https://cz.mouser.com/ProductDetail/Hirose-Connector/DF40C-100DS-04V51?qs=eDUdFcBPps2MEwbnuPvZzQ%3D%3D

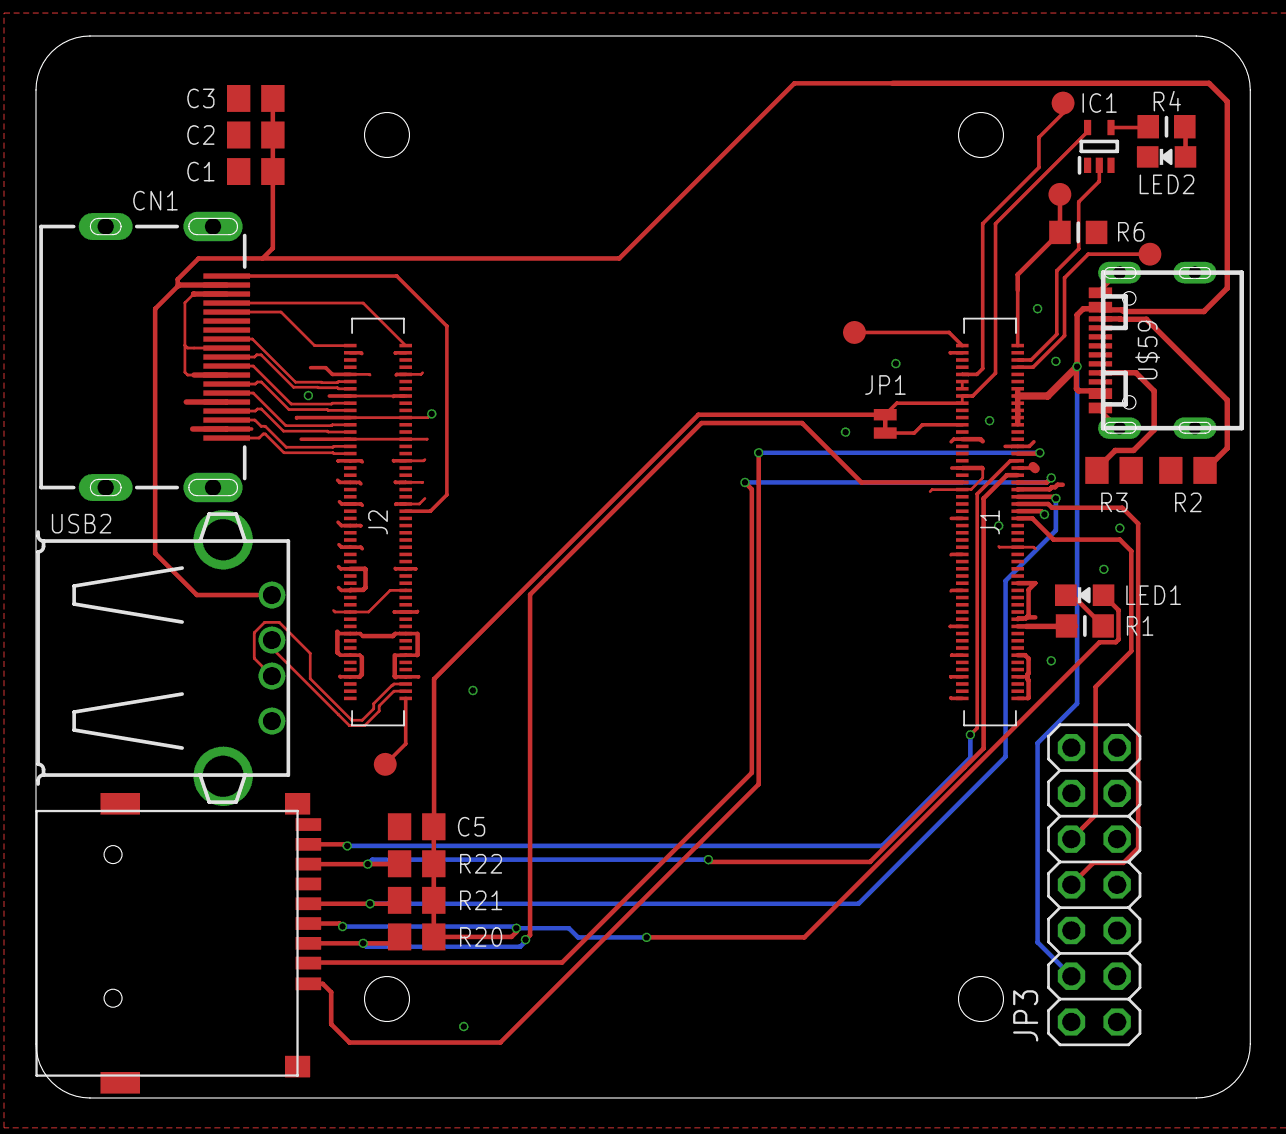
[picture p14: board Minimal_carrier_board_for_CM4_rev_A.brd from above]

Board: 2 copper layers, 67.5 x 59.0 mm, 28 parts (0 on the bottom side), 38 nets.

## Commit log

2021-01-06 Initial commit
    - pictures and files for Autodesk Eagle
    [Minimal_carrier_board_for_CM4_rev_A.brd, Minimal_carrier_board_for_CM4_rev_A.sch, Minimal_carrier_board_for_CM4_rev_B.brd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]
2021-01-11 Added connector for camera and DSI display
    [Minimal_carrier_board_for_CM4_rev_B.brd, Minimal_carrier_board_for_CM4_rev_B.sch]
2021-01-12 Update
    - moved USB-C, HDMI and USB-A connector to ensure that cables will not colide
    - changed USB-C and HDMI connector to my library so I can display width od the connectors
    - updated README accordingly
    [Minimal_carrier_board_for_CM4_rev_B.brd, Minimal_carrier_board_for_CM4_rev_B.sch]
2021-01-13 Update
    - renamed files so there are now 2 versions of rev.B:
    rev.B now have 15-pin connector for RPi camera module
    rev.B_alt have 22-pin connector for RPi camera module and DSI display
    - added/updated pictures for both versions of the board
    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
    [Minimal_carrier_board_for_CM4_rev_B_alt.brd, Minimal_carrier_board_for_CM4_rev_B_alt.sch]
2021-02-04 Aded pictures from CAD fro rev.B
2021-02-05 Update
    - updated README
    - upload rev.C files
    - upload rev.C images
    [Minimal_carrier_board_for_CM4_rev_C.brd, Minimal_carrier_board_for_CM4_rev_C.sch]
2023-02-06 Update
    - updated README.md
    - added rev.D and rev.E files (check README)
    [Minimal_carrier_board_for_CM4_rev_A .step, Minimal_carrier_board_for_CM4_rev_A.brd, Minimal_carrier_board_for_CM4_rev_C.brd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]

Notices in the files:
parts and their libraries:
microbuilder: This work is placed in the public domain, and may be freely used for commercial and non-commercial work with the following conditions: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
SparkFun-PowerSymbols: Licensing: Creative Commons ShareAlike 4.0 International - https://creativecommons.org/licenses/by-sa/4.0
